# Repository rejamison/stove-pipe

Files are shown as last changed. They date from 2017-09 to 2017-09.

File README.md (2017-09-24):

# Stove Pipe

This project was to build an RGB LED hat with a 5 x 18 grid display for my daughter to wear at the 2017 Mini Maker Faire in Seattle.



The hat is powered by a Pi Zero W connected to a [FadeCandy](https://github.com/scanlime/fadecandy) to control the LEDs.  The hat's structure is 3D printed.

The LED animation code is written in Node.js and the project includes an iOS/Android app to control the hat using HTML5/JS in [Apache Cordova](https://cordova.apache.org/).

I spent about 4 hours actively coding and another 4 hours modeling the parts for 3D printing.  The entire project took about 7 days, mostly unmonitored printing, and another 2-3 hours for assembly.

## 3D Printing

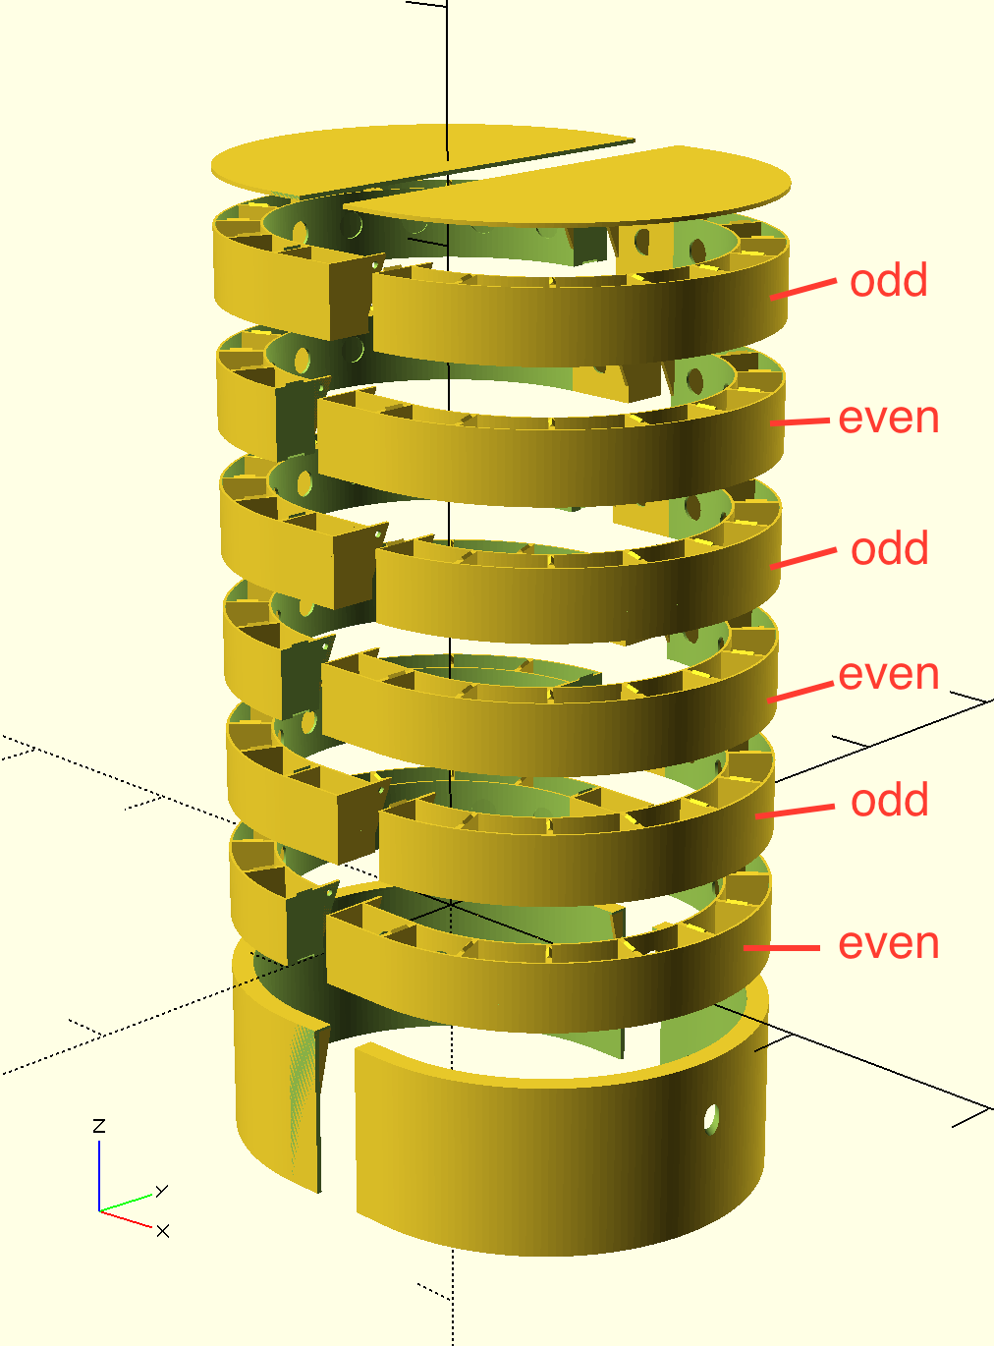
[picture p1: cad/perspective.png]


The hat is made up of 16 parts in 8 layers.  Each layer is split in two since I couldn't fit an entire ring onto my Ultimaker 2's 200x200 build plate.  The LED rings come in "odd" and "even" flavors so that the seam between halves doesn't line up between layers, making the assembled structure a bit sturdier.  If you have a larger printer, assembly could be greatly simplified by merging the halves of each layer together.

* red `top_half.stl`, red  `top_half.stl`
* green`ring_even_half.stl`, green `ring_even_half.stl`
* blue`ring_odd_half.stl`, blue `ring_odd_half.stl`
* green `ring_even_half.stl`, green `ring_even_half.stl`
* blue`ring_odd_half.stl`, blue `ring_odd_half.stl`
* green `ring_even_half.stl`, green `ring_even_half.stl`
* blue `ring_odd_half.stl`, blue `ring_odd_half.stl`
* yello `bottom_half_left.stl`, yello `bottom_half_right.stl`

`mount_plate.stl` is provided to mount the pi zero and fadecandy to, if desired.

STL files are located in the `cad/` sub-directory of the project and also on [Thingiverse](https://www.thingiverse.com/thing:2550326).

* Printed using white Polymaker Polymax PLA.
* 100% infill is required for even diffusion of the LEDs through the plastic.
* Full build with 6 LED layers requires ~1kg of filament.
* Sized for a 27" circumference, which accomodates a 23" head with room for ~1/2" padding, which is quite large.  You'll probably want to resize for your own head:
  * Figure out how big around your head is, then add 3" to the circumference to give room for about ~1/2" of padding.
  * Go to the OpenSCAD source file and play with the "pitch" parameter, which dictates the size of each LED cell in millimeters.  Smaller cells mean a smaller hat.
  * The "Outer Circumference in Inches" in the output console shows the current circumference based on the value you've set for "pitch".
  * Render each of the parts to STL files by commenting/uncommenting the appropriate module.

## Assembly

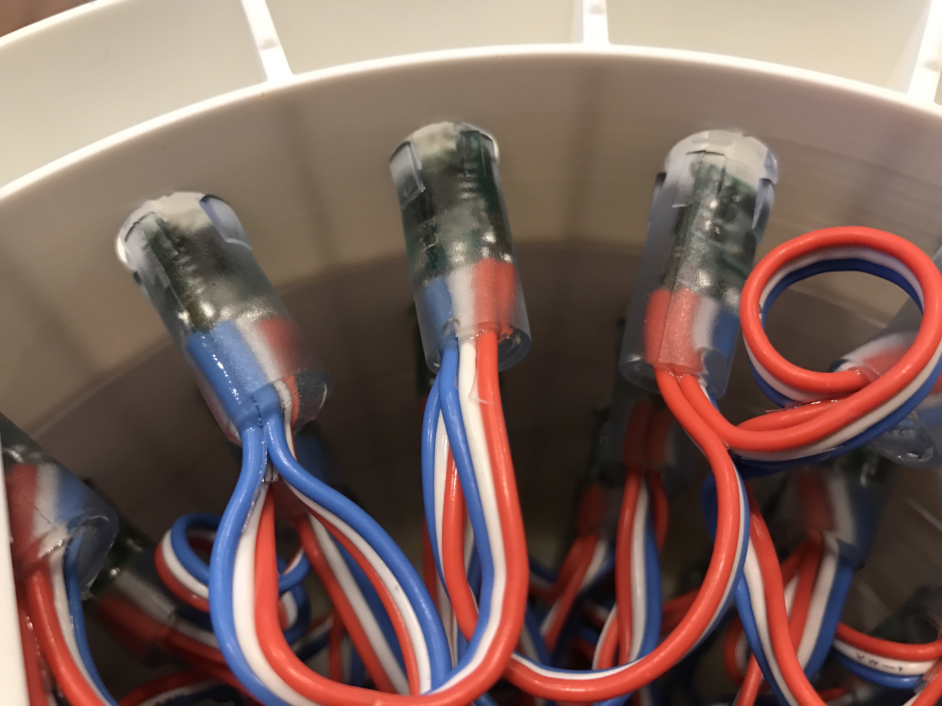
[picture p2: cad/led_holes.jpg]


Execept for the top, I glued the layers on top of each other with CA glue.  I used screws between the halves of the LED rings, but these weren't really necessary as the entire structure seemed to hold together well with just glue.  

Once the rings were assembled, I plugged the individual RGB LEDs on the strand into the holes in each cell.  The holes are sized to the built-in fastening tabs on the RGB strand I purchased, so no gluing necessary.  Be sure to layout the LEDs in a continuous spiral, starting at the top ring and as you complete a layer, being sure to start the next layer in the same column as the last.  The strands I purchased came with 50 LEDs, but I did NOT connect them end-to-end, since the FadeCandy addresses at most 64 LEDs on a single run.

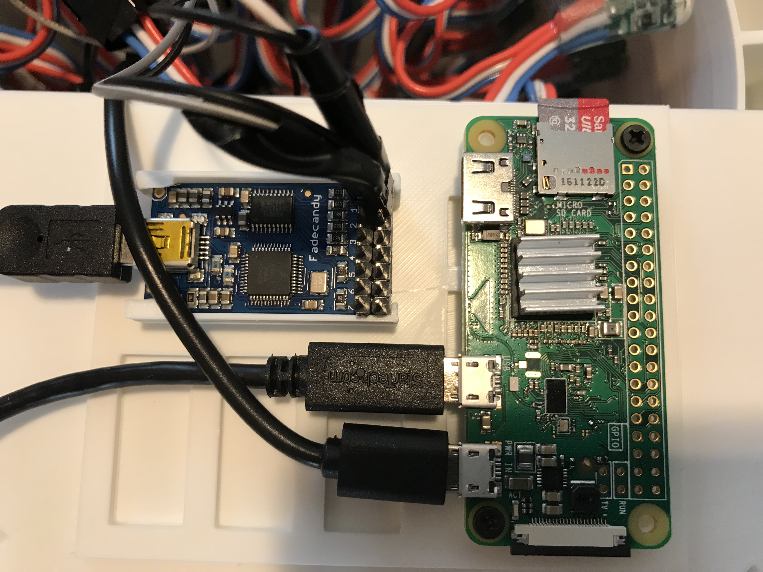
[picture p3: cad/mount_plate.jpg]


I soldered pin headers to the FadeCandy, rather than directly solder wires to the board, for easy future scavenging. 

I mounted the Pi using 2.5M screws to the mount plate and snapped in the FadeCandy.  They're connected to each other with a short Micro-USB to Mini-USB cable. 

The 0 and 1 LED banks of the FadeCandy each include a signal and ground connection.  The data pins of the first strand is connected to 0 and the second strand to 1.  

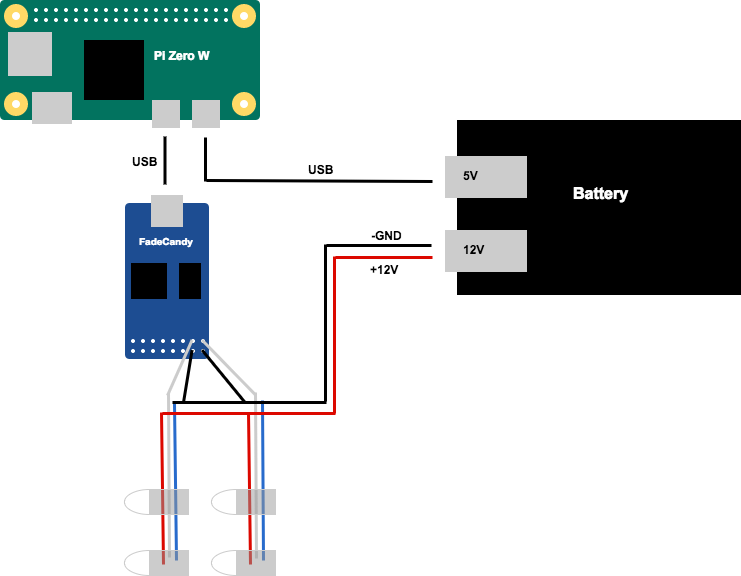
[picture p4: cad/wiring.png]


The FadeCandy ground pins should be shared with the ground of the LED strands, so I connected them to a terminal on a female 5.1mm x 2.1mm barrel jack connector.

The LED strands I chose use 12V vs. 5V, mostly because it was easier to get higher-amperage 12V batteries.  To create a 12V "rail", I connected both strands in parallel to the barrel jack, then connected a 6-foot extension to the jack.

Since the Pi uses 5V, I just connected a 6-foot Micro-USB to USB-B cable to the power connecter on the Pi.  I taped the 12V barrell jack and 5V USB cables together with some electrical tape to keep things tidy.  

**NOTE:  Since we're using both 12V and 5V, I recommend triple-checking your connections before applying power for the first time to avoid destroying your Pi.**

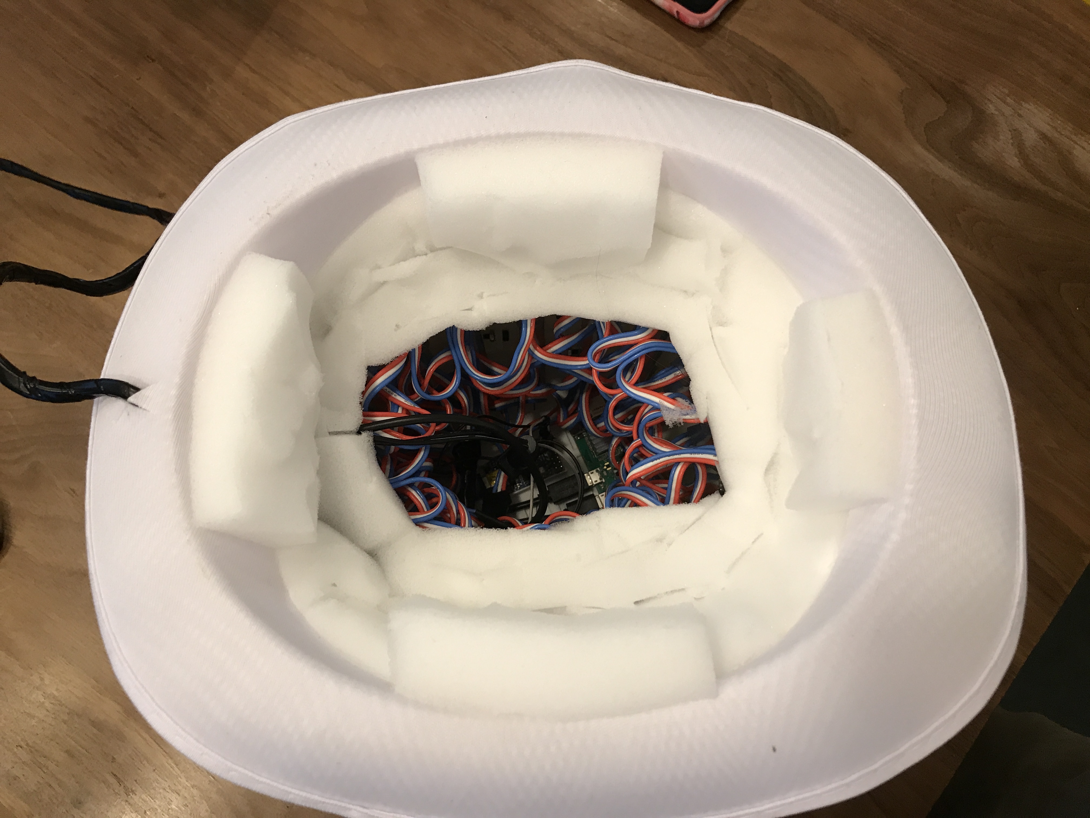
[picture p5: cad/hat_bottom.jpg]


I used high-density foam from a craft store to pad the bottom of the hat, cutting thin strips and building up layers as I tried it on my daughter's head until the fit was comfortable and stable.  

I used the brim of a cheap hat I bought on Amazon, cutting off the top of the hat and inserting the remainder into the bottom of the 3D printed tube.  This ended up being more trouble than it's worth, as it was finicky to fit right with its compound curve and ultimately made the top-heavy hat even more unstable.  For V2, I'd just print a brim, or tack on a bit of foam-board.

## Software Installation

I setup the Pi Zero W with the Raspian Stretch Lite image from [raspberrypi.org](https://www.raspberrypi.org/downloads/raspbian/), configuring wifi and enabling SSH in the `/boot/` image on the micro SD card before inserting it onto the pi.

After booting the Pi and SSH'ing in, I:
* Changed the password:  
  ```bash
  passwd
  ```
* Updated everything: 
  ```bash
  sudo apt-get update
  sudo apt-get upgrade
  ```
* Install git:  
  ```bash
  sudo apt-get install git
  ```
* [Install nvm](https://github.com/creationix/nvm#install-script).
* [Install node using nvm](https://github.com/creationix/nvm#usage).
* [Changed the hostname](https://thepihut.com/blogs/raspberry-pi-tutorials/19668676-renaming-your-raspberry-pi-the-hostname) to `stove-pipe`.

I grabbed the project code inside the `/home/pi` directory:

```bash
git clone git@github.com:rejamison/stove-pipe.git
cd stove-pipe
npm install
```

FadeCandy provides a server that gives you a web-based interface for interacting with the LEDs.  I [built the server](https://github.com/scanlime/fadecandy/tree/master/server).  To test things out, run the server in the background and try running the LED animation script:

```bash
cd /home/pi/fadecandy/server
fcserver &
cd /home/pi/stove-pipe
node index.js FadeCandy
```

You can also tell the animation script to render the animation to the console:

```bash
node index.js Console
```

If you're developing your own animations, I recommend doing so on your development machine and connecting remotely to the FadeCandy server on the Pi (vs. trying to develop locally on the Pi).  To do that, just modify the hostname in [index.js](https://github.com/rejamison/stove-pipe/blob/master/index.js) to your Pi's:

```javascript
var client = new OPC('stove-pipe.local', 7890);
```

**NOTE: Be careful about accidentally pushing this change up to the Pi.  It will work fine as long as it's connected to wifi, but you'll find it doesn't work if it's not able to connect to a network because the `.local` hostname won't route to anything.**
 
Once everything is good to go, I moved the binary to a global bin directory and set the server and my LED animation script to run on boot:

```bash
sudo mv fcserver /usr/local/bin
sudo nano /etc/rc.local
```

Adding the following to `rc.local` before the last `exit 0` line:

```bash
/usr/local/bin/fcserver /home/pi/stove-pipe/fcserver_config.json >/var/log/fcserver.log 2>&1 &
/home/pi/.nvm/versions/node/v8.5.0/bin/node /home/pi/stove-pipe/index.js FadeCandy
```

**NOTE:  You might need to adjust the node path above depending on what's the latest when you install using NVM.  You can figure it out by running: `which node`.**

Reboot the Pi and the animation should start running!

To control the hat, I built a BLE characteristic into the animation script to control which animation is playing and built a small mobile app to connect to the pi.  To build the app using Apache Cordova, from your development machine:
* [Setup Apache Cordova for iOS or Android](https://cordova.apache.org/docs/en/latest/).
* Grab the development project:  
  ```bash
  git clone git@github.com:rejamison/stove-pipe.git
  ```
* Install the app using cordova.  
  * For Android:  
    ```bash
    cd stove-pipe/app
    cordova platform add android
    cordova run android
    ```
  * For iOS:  
    ```bash
    cd stove-pipe/app
    cordova platform add ios
    cordova run ios
    ```

## Usage

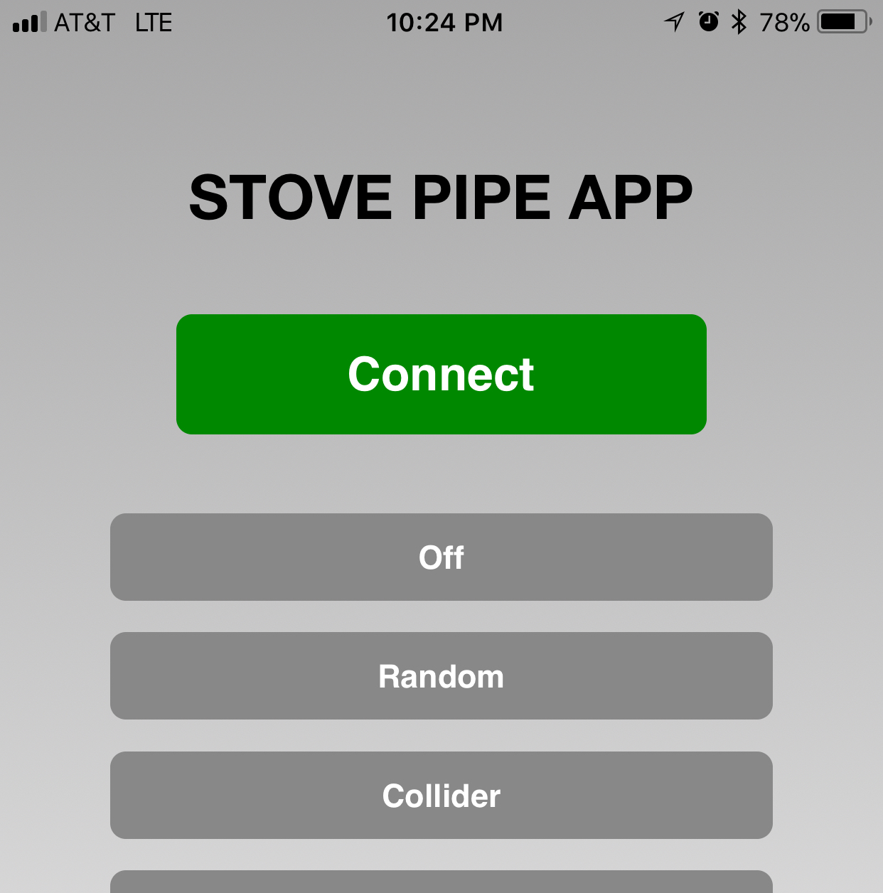
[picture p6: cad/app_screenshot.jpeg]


To use the app, just open it up on your device and click the "Connect" button.  After it connects, all the animation buttons should turn green and you should be able to switch the running animation by clicking any of the buttons.

If the app has trouble connecting, it may be because you're using a different hostname for the Pi.  You can change the `BT_DEVICE_NAME` parameter in the app's code [app/www/js/index.js](https://github.com/rejamison/stove-pipe/blob/master/app/www/js/index.js) or change the hostname of the device to `stove-pipe`.

## Bill of Materials

|Tools|
|---|
|CA Glue|
|Soldering Iron & Solder|
|Wire Cutters|
|Hobby Knife|

|Part|Qty|Cost Each|Total Cost|Link|Note|
|---|---|---|---|---|---|
|ALITOVE LED Strand (12V, 50 LEDs each)|2|$33|$66|[Amazon](https://www.amazon.com/ALITOVE-Individually-Addressable-Non-waterproof-Raspberry/dp/B014R5PC42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)||
|FadeCandy|1|$24|$24|[Amazon](https://www.amazon.com/Adafruit-FadeCandy-Dithering-USB-Controlled-NeoPixels/dp/B00JHJJF9W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)||
|Pi Zero W|1|$25|$25|[Amazon](https://www.amazon.com/CanaKit-Raspberry-Wireless-Official-Supply/dp/B071L2ZQZX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)|You don't need the case or power supply for this build, and can save $15 if you can find a barebones Zero W.|
|8GB Micro SD|1|$9|$9|[Amazon](https://www.amazon.com/gp/product/B010Q57SEE/ref=oh_aui_detailpage_o00_s00?ie=UTF8&psc=1)|8GB is overkill, but smaller wasn't really cheaper.|
|Micro USB to Mini USB Adapter|1|$4|$4|[Amazon](https://www.amazon.com/gp/product/B018M8YNDG/ref=od_aui_detailpages01?ie=UTF8&psc=1)|Wish they made smaller ones of these, and cheaper.  You could patch a cable together or even solder directly onto the FadeCandy board, but I prefered to keep this pluggable for future scavenging.|
|6" Mini USB Cable|1|$4|$4|[Amazon](https://www.amazon.com/gp/product/B00VU7PTKI/ref=oh_aui_detailpage_o02_s01?ie=UTF8&psc=1)||
|2.1mm x 5.5mm Male Jack|1|$1|$1|[Amazon](https://www.amazon.com/Wsdcam-5-5x2-1mm-Adapter-Connector-Security/dp/B0127J7NWE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)||
|6" Male/Female 2.1mm x 5.5mm Cable|1|$7|$7|[Amazon](https://www.amazon.com/gp/product/B00FTH6WNS/ref=oh_aui_detailpage_o02_s00?ie=UTF8&psc=1)|Begrudgingly bought this.  You could build your own cable, but considering the amperage it would carry, I decided to splurge.|
|TalentCell 12V@6A/5V@2A 26000mAh Li-Ion Battery|1|$65|$65|[Amazon](https://www.amazon.com/gp/product/B016BJCRUO/ref=oh_aui_detailpage_o07_s00?ie=UTF8&psc=1)|This is overkill, but I wanted a battery rated at 12V@6A to drive the LEDs at peak brightness.  The capacity means the hat can run all-day, maybe a couple of days.  Here's a cheaper one for $34 (and lighter too) rated for 12V@3A and 12000mAk, you'll just need to reduce the LED brightness:  [Amazon](https://www.amazon.com/TalentCell-Rechargeable-12000mAh-Multi-led-indicator/dp/B00ME3ZH7C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).  The battery is a handy component and easily re-used, so I consider it an investment.|
|White Top Hat|1|$9|$9|[Amazon](https://www.amazon.com/gp/product/B003E98N9O/ref=oh_aui_detailpage_o03_s00?ie=UTF8&psc=1)|See above, I attempted to use this for it's brim, but would just 3D print one instead.|
|High Density Foam Padding|1|$12|$12|[Amazon](https://www.amazon.com/FoamTouch-Upholstery-Cushion-Density-Height/dp/B01K01HJZM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)||
|White Polymaker Polymax 750g|1|$46|$46|[Printed Solid](https://printedsolid.com/products/polymaker-polymax-pla-3mm-x-750g?variant=35756291468)|Polymaker is my go-to filament, by no means the cheapest you can get.  Used nearly an entire spool of 750g for this build.|
|2.5M Screws|1|$0|$0|[Amazon](https://www.amazon.com/Slaxry-Notebook-Laptop-SAMSUNG-TOSHIBA/dp/B01M04WWVV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)|2.5M screws are a little hard to find, but an easy way to get them is to buy a screw kit assortment for laptops for a few dollars on Amazon.  I find the other sizes included to be pretty handy for projects.|
||||**$272**||

Prices as of 9/17/17.

Wow, more than I expected before adding it up.  Of course, I had most of this stuff laying around, so my only real outlay was the LED strands and the cables.  Everything is scavengable except the filament.

If I were building it again, I'd probably switch to an LED strip, which is a lot cheaper per LED (~$15 / 100 LEDs vs. $66 / 100 LEDs) and would weigh quite a bit less.  The cheaper battery, DIY cables, a barebones Pi Zero W and ditching the hat saves another $66, for a hypothetical total of $165.

If you're really looking for a cheap project, then you can get 1kg of cheap PLA for ~$25 and switch to a nano Arduino for ~$5 and skip the FadeCandy, though you'd have to roll your own code and drop the BLE support.  That gets the project into the ~$90-100 range which is mostly battery, filament and LEDs.

## Future Ideas

I'll probably never get to these, but here's some stuff I'd do with more time:

* Add a BLE characteristic that allows you to shutdown the Pi cleanly.
* Switch to an LED strip, instead of the bulky strands.

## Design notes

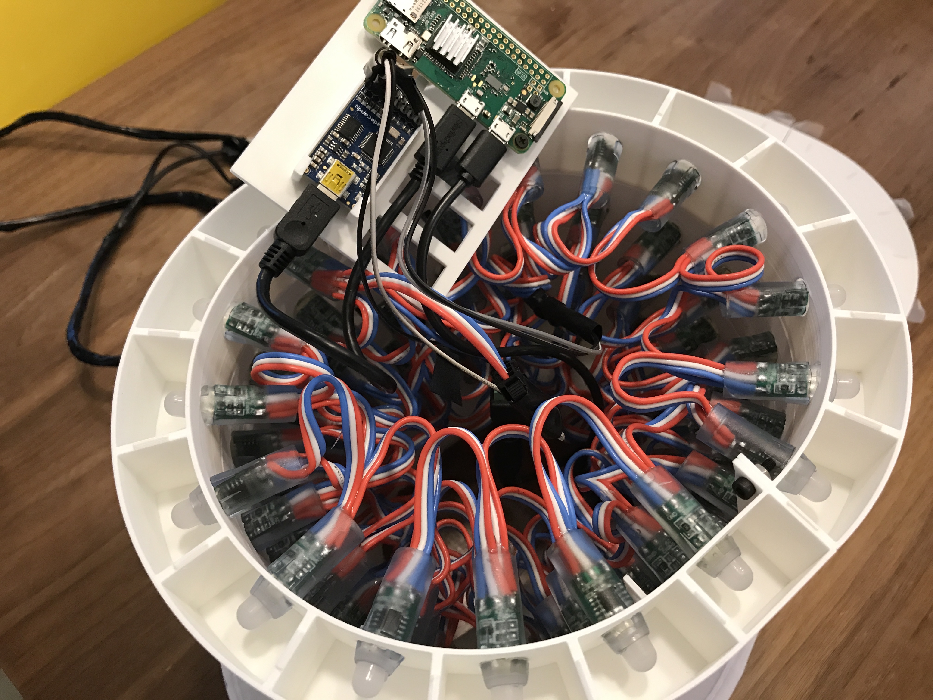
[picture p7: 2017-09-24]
cad/hat_top.jpg

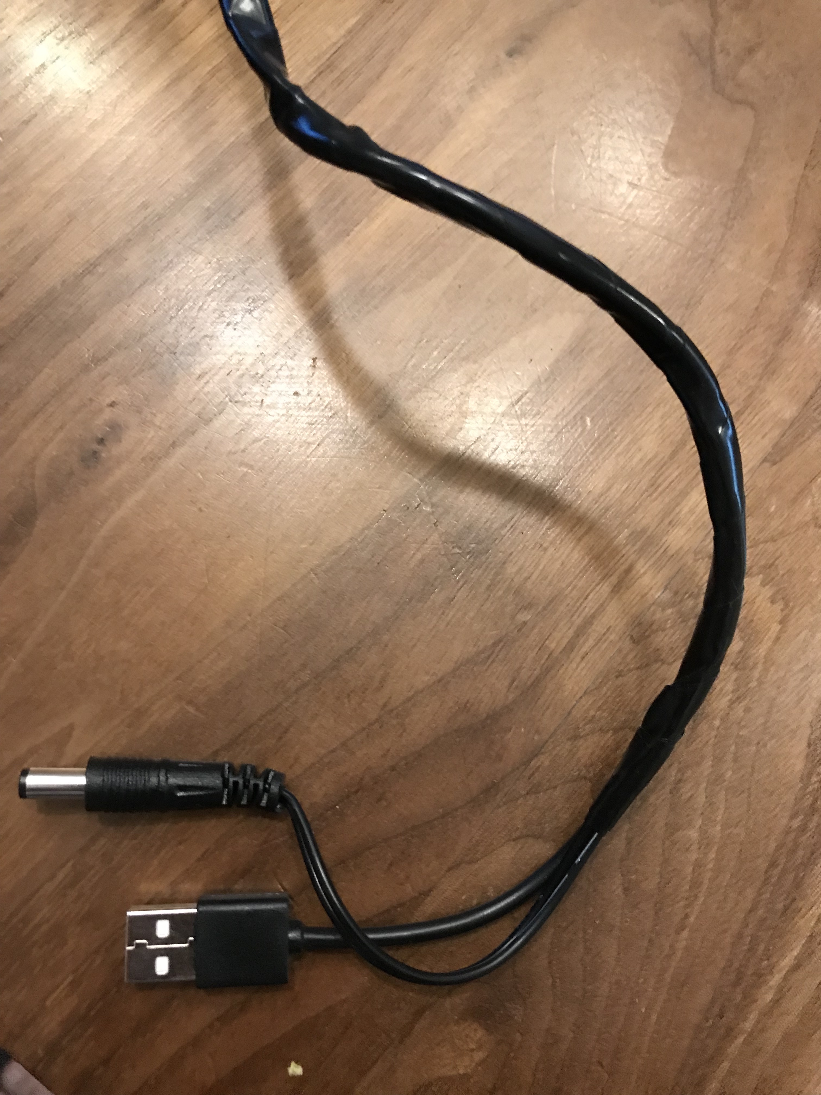
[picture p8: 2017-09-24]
cad/wrapped_cable.jpg

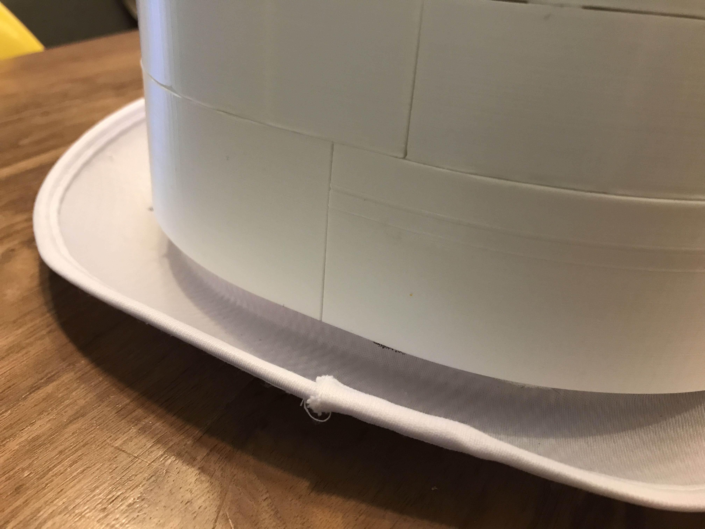
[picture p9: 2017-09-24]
cad/hat_brim.jpg

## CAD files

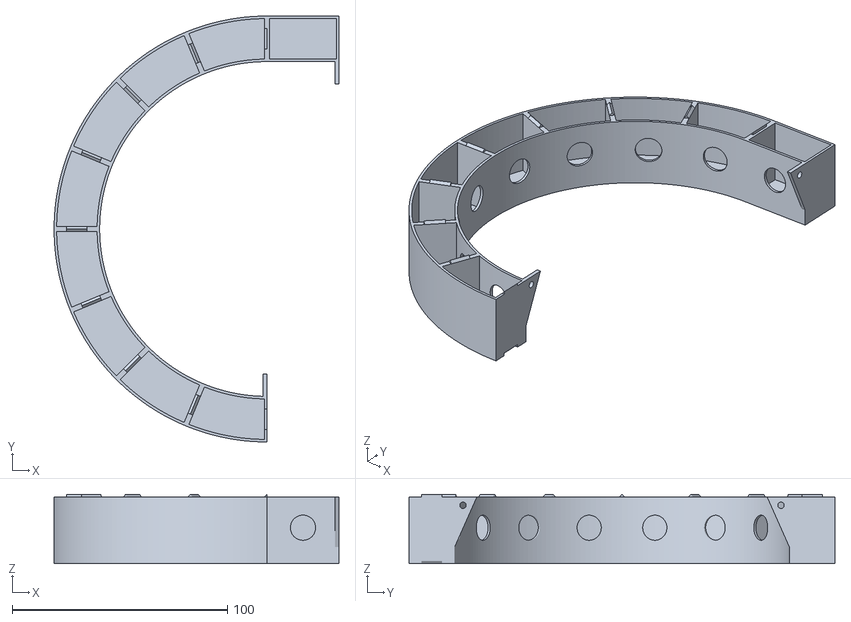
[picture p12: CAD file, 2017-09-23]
cad/ring_even_half.stl
132.3 x 197.9 x 32.2

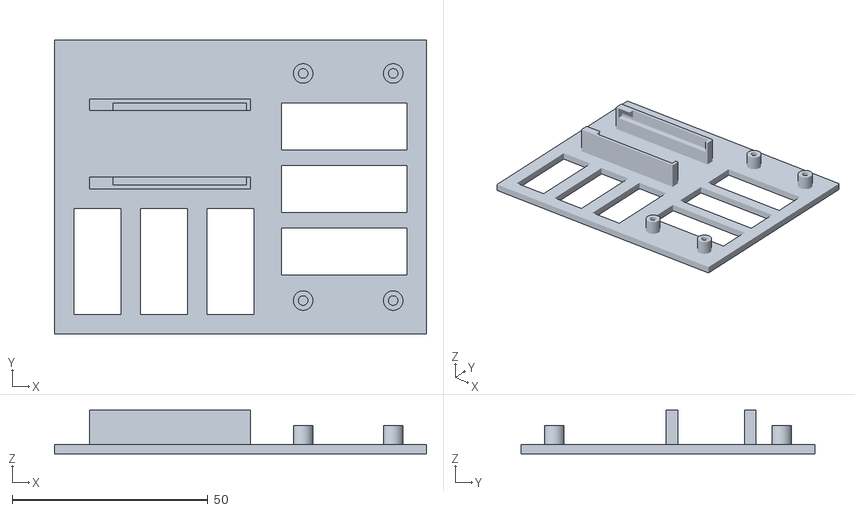
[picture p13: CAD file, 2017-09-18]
cad/mount_plate.stl
95.0 x 75.0 x 11.2

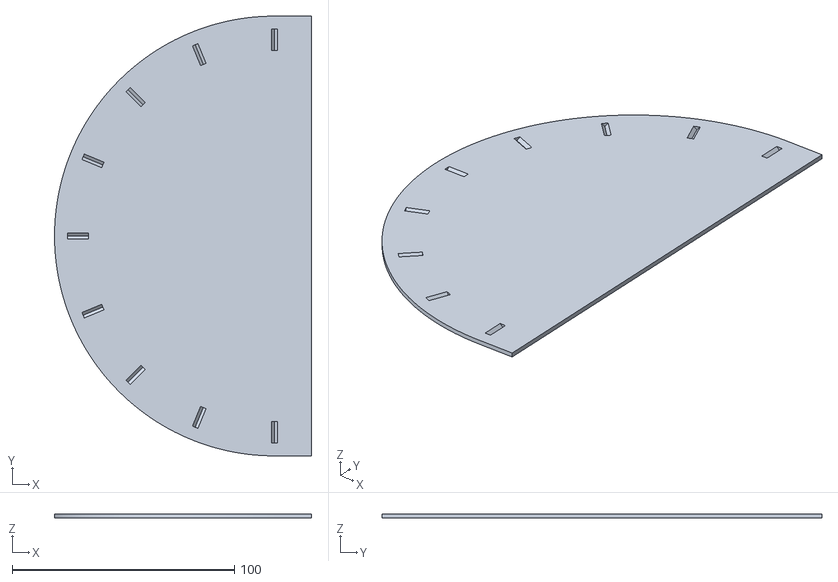
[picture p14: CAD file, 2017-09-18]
cad/top_half.stl
115.6 x 197.9 x 1.80

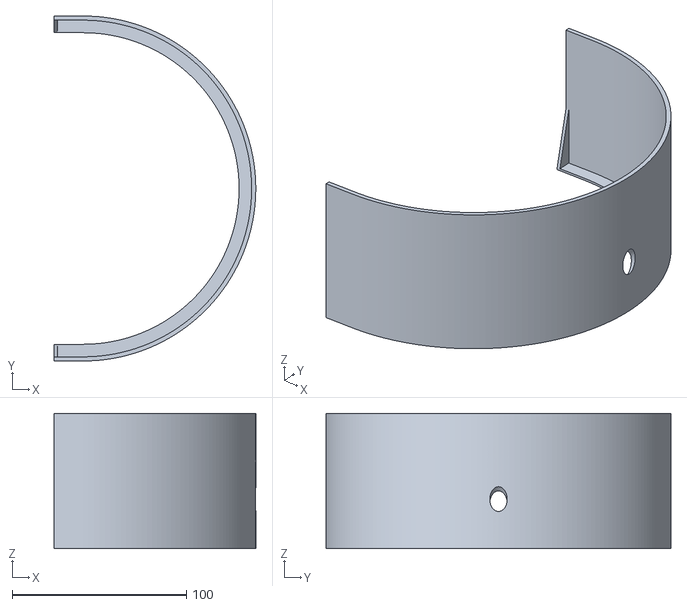
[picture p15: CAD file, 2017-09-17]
cad/bottom_half_right.stl
115.6 x 197.9 x 77.5

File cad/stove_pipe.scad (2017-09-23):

$fn = 200;

pitch = 31;
led_per_stack = 1;
height = pitch * led_per_stack;
led_per_layer = 16;
inner_radius = (pitch * led_per_layer) / (2 * 3.14159);
wall_depth = 1.2;
led_radius = (11.5+.2)/2;
led_cell_depth=20;
notch_diag=(wall_depth*2);
notch_height=(notch_diag)/1.4142;

echo("Inner Diameter in MM", (inner_radius * 2));
echo("Outer Diameter in MM", ((inner_radius + 10) * 2));
echo("Outer Circumference in Inches", (((inner_radius + led_cell_depth) * 2 * 3.14159) + (pitch * 2)) / 25.4);

//ring_even_half_left();
//ring_even_half_right();  // same as left, just rotated and translated
ring_odd_half_left();
//ring_odd_half_right();  // same as left just rotated and translated
//top_half_left();
//top_half_right();  // same as left, just rotated and translated
//mount_plate();
//alt_bottom_half_left();
//alt_bottom_half_right();  // this one is different, as it includes a hole for a cable to pass through

//exploded();

module exploded() {
    gap = 25;

    translate([0,0,0]) ring_even_half_left();
    translate([gap,0,0]) ring_even_half_right();

    translate([0,0,height + gap]) ring_odd_half_left();
    translate([gap,0,height + gap]) ring_odd_half_right();

    translate([0,0,(height + gap) * 2]) ring_even_half_left();
    translate([gap,0,(height + gap) * 2]) ring_even_half_right();

    translate([0,0,(height + gap) * 3]) ring_odd_half_left();
    translate([gap,0,(height + gap) * 3]) ring_odd_half_right();

    translate([0,0,(height + gap) * 4]) ring_even_half_left();
    translate([gap,0,(height + gap) * 4]) ring_even_half_right();

    translate([0,0,(height + gap) * 5]) ring_odd_half_left();
    translate([gap,0,(height + gap) * 5]) ring_odd_half_right();

    translate([0,0,(height + gap) * 6]) rotate([180,0,0]) top_half_left();
    translate([gap,0,(height + gap) * 6]) rotate([180,0,0]) top_half_right();
    
    translate([0,0,-gap]) rotate([180,0,0])  alt_bottom_half_left();
    translate([gap,0,-gap]) rotate([180,0,0]) alt_bottom_half_right();
}

module bottom_half_left() {
    difference() {
        union() {
            cylinder(r=inner_radius+led_cell_depth,h=pitch*1.5);
            translate([0,-(inner_radius+led_cell_depth),0]) cube([(pitch/2)+wall_depth, (inner_radius+led_cell_depth) * 2, pitch*1.5]);
        }
        translate([0,0,pitch/2-.01]) cylinder(r1=inner_radius-wall_depth, r2=inner_radius-wall_depth*4+led_cell_depth ,h=pitch+.02);
        translate([0,0,-.01]) cylinder(r=inner_radius-wall_depth,h=pitch+.02);
        translate([(pitch/2)+wall_depth,-(inner_radius+led_cell_depth),-1]) cube([500, (inner_radius+led_cell_depth) * 2, pitch*1.5+2]);
        translate([0,-(inner_radius-wall_depth),-1]) cube([500, (inner_radius-wall_depth) * 2, pitch+2]);
        translate([0+.01,inner_radius-wall_depth-.01,pitch/2-.01]) rotated_prism((pitch/2)+wall_depth,led_cell_depth-wall_depth*3,pitch+.02,180,0,0);
        translate([0+.01,-inner_radius+wall_depth-led_cell_depth+wall_depth*3+.01,pitch/2-.01]) rotated_prism((pitch/2)+wall_depth,led_cell_depth-wall_depth*3,pitch+.02,180,0,180);
    }
}

module bottom_half_right() {
    difference() {
        translate([pitch+wall_depth*2,0,0]) rotate([0,0,180]) bottom_half_left();
        translate([inner_radius-6,0,-pitch]) rotate([0,45,0]) cylinder(d=10,h=100);
    }
}

module alt_bottom_half_left() {
    difference() {
        union() {
            cylinder(r=inner_radius+led_cell_depth,h=pitch*2.5);
            translate([0,-(inner_radius+led_cell_depth),0]) cube([(pitch/2)+wall_depth, (inner_radius+led_cell_depth) * 2, pitch*2.5]);
        }
        translate([0,0,wall_depth-.01]) cylinder(r=inner_radius-wall_depth*2+led_cell_depth ,h=pitch*2.5+.02);
        translate([0,0,-.01]) cylinder(r=inner_radius-wall_depth*8+led_cell_depth,h=pitch+.02);
        translate([(pitch/2)+wall_depth,-(inner_radius+led_cell_depth),-1]) cube([500, (inner_radius+led_cell_depth) * 2, pitch*2.5+2]);
        translate([0,-(inner_radius+led_cell_depth-wall_depth*2),wall_depth]) cube([100, (inner_radius+led_cell_depth-wall_depth*2) * 2, pitch*2.5+2]);
        translate([0,-(inner_radius+led_cell_depth-wall_depth*8),-1]) cube([100, (inner_radius+led_cell_depth-wall_depth*8) * 2, pitch*2.5+2]);
    }
    // tabs
    translate([pitch/2-wall_depth*.5,(inner_radius+led_cell_depth-wall_depth*8),wall_depth]) rotated_prism(wall_depth*1.5,wall_depth*6,height,0,0,0);
    translate([pitch/2-wall_depth*.5,-(inner_radius+led_cell_depth-wall_depth*2),wall_depth]) rotated_prism(wall_depth*1.5,wall_depth*6,height,0,0,180);
}

module alt_bottom_half_right() {
    difference() {
        translate([pitch+wall_depth*2,0,0]) rotate([0,0,180]) alt_bottom_half_left();
        translate([inner_radius-6,0,-pitch]) rotate([0,45,0]) cylinder(d=10,h=100);
    }
}

module top_half_left() {
    difference() {
        union() {
            cylinder(r=inner_radius+led_cell_depth,h=wall_depth*1.5);
            translate([0,-(inner_radius+led_cell_depth),0]) cube([pitch/2+wall_depth, (inner_radius+led_cell_depth) * 2, wall_depth*1.5]);
        }
        translate([pitch/2+wall_depth,-(inner_radius+led_cell_depth),-1]) cube([500, (inner_radius+led_cell_depth) * 2, wall_depth*1.5+2]);
        for(i = [0:1:led_per_layer - 1]) {
            translate([0,0,wall_depth*1.5]) rotate([45,0,i * (360 / led_per_layer)]) translate([inner_radius+((led_cell_depth-wall_depth)/4)-.1,-(notch_height)/2-.1,-(notch_height)/2-.1]) cube([(led_cell_depth-wall_depth)/2+.2,notch_height+.2,notch_height+.2]);
        }
    }
}

module top_half_right() {
    translate([pitch+wall_depth*2,0,0]) rotate([0,0,180]) top_half_left();
}

module mount_plate() {
    difference() {
        translate([-60,-55,0]) cube([95,75,wall_depth*2]);
        translate([-2,-8,-.1]) cube([32,12,50]);
        translate([-2,-24,-.1]) cube([32,12,50]);
        translate([-2,-40,-.1]) cube([32,12,50]);
        translate([-55,-50,-.1]) cube([12,27,50]);
        translate([-38,-50,-.1]) cube([12,27,50]);
        translate([-21,-50,-.1]) cube([12,27,50]);
    }
    translate([-10,5,wall_depth]) rotate([0,0,180]) fadecandy_mount();
    translate([30,-50,wall_depth]) rotate([0,0,90]) pi_zero_mount();
}

module fadecandy_mount() {
    difference() {
        cube([41,23,10]);
        translate([1,1,6]) cube([39,21,10]);
        translate([-1,3,-1]) cube([43,17,12]);
    }
    translate([35,19.5,7.5]) rotated_prism(5, 3, 2, 90, 0 ,0);
    translate([35,0.5,7.5]) rotated_prism(5, 3, 2, 90, 0, 180);
}

module pi_zero_mount() {
    translate([0+3.5,0+3.5,0]) difference() {
        cylinder(d=5,h=6);
        translate([0,0,-.01]) cylinder(d=2.45,h=6+.02);
    }
    translate([58+3.5,0+3.5,0]) difference() {
        cylinder(d=5,h=6);
        translate([0,0,-.01]) cylinder(d=2.45,h=6+.02);
    }
    translate([0+3.5,23+3.5,0]) difference() {
        cylinder(d=5,h=6);
        translate([0,0,-.01]) cylinder(d=2.45,h=6+.02);
    }
    translate([58+3.5,23+3.5,0]) difference() {
        cylinder(d=5,h=6);
        translate([0,0,-.01]) cylinder(d=2.45,h=6+.02);
    }
}

module ring_even_half_left() {
    difference() {
        union() {
            // outer ring
            difference() {
                cylinder(r=inner_radius+led_cell_depth,h=height);
                translate([0,0,-1]) cylinder(r=inner_radius+led_cell_depth-wall_depth,h=height+2);
            }

            // inner ring and ribs
            difference() {
                union() {
                    cylinder(r=inner_radius,h=height);
                    for(i = [0:1:led_per_layer - 1]) {
                        rotate([0,0,i * (360 / led_per_layer)]) translate([inner_radius-wall_depth,-(wall_depth),0]) cube([led_cell_depth,wall_depth*2,height]);
                        translate([0,0,height]) rotate([45,0,i * (360 / led_per_layer)]) translate([inner_radius+((led_cell_depth-wall_depth)/4),-(notch_height)/2,-(notch_height)/2]) cube([(led_cell_depth-wall_depth)/2,notch_height,notch_height]);
                    }
                    for(i = [0:1:led_per_stack - 1]) {
                        translate([0,0,pitch*i]) cylinder(r=inner_radius+led_cell_depth,h=wall_depth*2);
                    }
                }
                translate([0,0,-1]) cylinder(r=inner_radius-wall_depth,h=height+10);
                for(i = [0:1:led_per_layer - 1]) {
                    rotate([45,0,i * (360 / led_per_layer)]) translate([inner_radius+((led_cell_depth-wall_depth)/4)-.1,-(notch_height)/2-.1,-(notch_height)/2-.1]) cube([(led_cell_depth-wall_depth)/2+.2,notch_height+.2,notch_height+.2]);
                    rotate([90,0,(360 / led_per_layer) * (i + 0.5)]) translate([0,pitch/2 + wall_depth,wall_depth]) cylinder(r=led_radius,h=inner_radius);
                }
            }
        } 
        
        translate([0,-100,-100]) cube([200,200,200]);
    }
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

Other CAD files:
cad/ring_odd_half.stl
cad/bottom_half_left.stl

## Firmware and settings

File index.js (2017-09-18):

var process = require('process');
var chalk = require('chalk');
var OPC = require('./opc');
var bleno = require('bleno');
var StovePipeCharacteristic = require('./characteristic');

var FRAME_RATE = 12;
var font = [
    "  X   XXXX   XXXX XXX   XXXX  XXXXX  XXX  X   X  XXX      X X  X  X     X   X X   X  XXX  XXX    XXX  XXXX   XXX  XXXXX X   X X   X X   X X   X X   X XXXXX ",
    " X X  X   X X     X  X  X     X     X   X X   X   X       X X X   X     XX XX XX  X X   X X  X  X   X X   X XX      X   X   X X   X X   X  X X   X X     X  ",
    "XXXXX XXXX  X     X   X XXX   XXX   X     XXXXX   X       X XX    X     X X X X X X X   X XXX   X   X XXXX   XX     X   X   X  X X  X X X   X     X     X   ",
    "X   X X   X X     X  X  X     X     X  XX X   X   X   X   X X X   X     X   X X  XX X   X X     X  XX X  X     XX   X   X   X   X   XX XX  X X    X    X    ",
    "X   X XXXX   XXXX XXX   XXXX  X      XXX  X   X  XXX   XXX  X  X  XXXXX X   X X   X  XXX  X      XXXX X   X  XXX    X    XXX    X    X X  X   X   X   XXXXX "
];
var pacman = [
    "  XXX     XXXX  ",
    " XXXXX   XXXX   ",
    "XXXXXXX XXX     ",
    " XXXXX   XXXX   ",
    "  XXX     XXXX  "
];
var client = new OPC('127.0.0.1', 7890);

function hsvToRgb(h, s, v) {
    var r, g, b, i, f, p, q, t;
    if (arguments.length === 1) {
        s = h.s, v = h.v, h = h.h;
    }
    i = Math.floor(h * 6);
    f = h * 6 - i;
    p = v * (1 - s);
    q = v * (1 - f * s);
    t = v * (1 - (1 - f) * s);
    switch (i % 6) {
        case 0: r = v, g = t, b = p; break;
        case 1: r = q, g = v, b = p; break;
        case 2: r = p, g = v, b = t; break;
        case 3: r = p, g = q, b = v; break;
        case 4: r = t, g = p, b = v; break;
        case 5: r = v, g = p, b = q; break;
    }
    return new RGB(Math.round(r * 255), Math.round(g * 255), Math.round(b * 255));
}

function RGB(r, g, b) {
    this.r = r;
    this.g = g;
    this.b = b;
}

function Canvas() {
    this.buffer = [
        [new RGB(255,255,255),new RGB(255,255,255),new RGB(255,255,255),new RGB(255,255,255),new RGB(255,255,255),new RGB(255,255,255),new RGB(255,255,255),new RGB(255,255,255),new RGB(255,255,255),new RGB(255,255,255),new RGB(255,255,255),new RGB(255,255,255),new RGB(255,255,255),new RGB(255,255,255),new RGB(255,255,255),new RGB(255,255,255),new RGB(255,255,255),new RGB(255,255,255)],
        [new RGB(255,255,255),new RGB(255,255,255),new RGB(255,255,255),new RGB(255,255,255),new RGB(255,255,255),new RGB(255,255,255),new RGB(255,255,255),new RGB(255,255,255),new RGB(255,255,255),new RGB(255,255,255),new RGB(255,255,255),new RGB(255,255,255),new RGB(255,255,255),new RGB(255,255,255),new RGB(255,255,255),new RGB(255,255,255),new RGB(255,255,255),new RGB(255,255,255)],
        [new RGB(255,255,255),new RGB(255,255,255),new RGB(255,255,255),new RGB(255,255,255),new RGB(255,255,255),new RGB(255,255,255),new RGB(255,255,255),new RGB(255,255,255),new RGB(255,255,255),new RGB(255,255,255),new RGB(255,255,255),new RGB(255,255,255),new RGB(255,255,255),new RGB(255,255,255),new RGB(255,255,255),new RGB(255,255,255),new RGB(255,255,255),new RGB(255,255,255)],
        [new RGB(255,255,255),new RGB(255,255,255),new RGB(255,255,255),new RGB(255,255,255),new RGB(255,255,255),new RGB(255,255,255),new RGB(255,255,255),new RGB(255,255,255),new RGB(255,255,255),new RGB(255,255,255),new RGB(255,255,255),new RGB(255,255,255),new RGB(255,255,255),new RGB(255,255,255),new RGB(255,255,255),new RGB(255,255,255),new RGB(255,255,255),new RGB(255,255,255)],
        [new RGB(255,255,255),new RGB(255,255,255),new RGB(255,255,255),new RGB(255,255,255),new RGB(255,255,255),new RGB(255,255,255),new RGB(255,255,255),new RGB(255,255,255),new RGB(255,255,255),new RGB(255,255,255),new RGB(255,255,255),new RGB(255,255,255),new RGB(255,255,255),new RGB(255,255,255),new RGB(255,255,255),new RGB(255,255,255),new RGB(255,255,255),new RGB(255,255,255)],
    ];

    this.animationIndex = 0;
    this.height = this.buffer.length;
    this.width = this.buffer[0].length;
    this.shouldConsole = false;
    this.shouldFadeCandy = false;
    this.animations = [];

    this.initialize = function(renderToConsole, renderToFadeCandy) {
        console.log('Width: ' + this.width);
        console.log('Height: ' + this.height);
        this.shouldConsole = renderToConsole ? true : false;
        this.shouldFadeCandy = renderToFadeCandy ? true : false;

        bleno.on('stateChange', function(state) {
            console.log('on -> stateChange: ' + state);

            if (state === 'poweredOn') {
                bleno.startAdvertising('stove-pipe', ['ec00']);
            } else {
                bleno.stopAdvertising();
            }
        });

        var that = this;
        bleno.on('advertisingStart', function(error) {
            console.log('on -> advertisingStart: ' + (error ? 'error ' + error : 'success'));

            if (!error) {
                bleno.setServices([
                    new bleno.PrimaryService({
                        uuid: 'ec00',
                        characteristics: [
                            new StovePipeCharacteristic(that)
                        ]
                    })
                ]);
            }
        });

        if(this.shouldConsole) {
            // spit out some newlines for rendering to the console
            for(var x = 0; x < this.height; x++) {
                process.stdout.write('\n');
            }
        }

        this.animations.push(new Random());             // 0    0x00
        this.animations.push(new Collider());           // 1    0x01
        this.animations.push(new PulsingPixels());      // 2    0x02
        this.animations.push(new RotatingRainbow());    // 3    0x03
        this.animations.push(new Equalizer());          // 4    0x04
        this.animations.push(new GrowingLine());        // 5    0x05
        this.animations.push(new RacingDot());          // 6    0x06
        this.animations.push(new RacingLine());         // 7    0x07
        this.animations.push(new ScrollingText('MAKER FAIRE', new RGB(255,0,0)));
        this.animations.push(new ScrollingText('PENELOPE RULES', new RGB(0,0,255)));
        this.animations.push(new Rain());               // 10   0x0A
        this.animations.push(new Fireworks());          // 11   0x0B
        this.animations.push(new Pacman());             // 12   0x0C
        this.animations.push(new Off());                // 13   0x0D
        this.animations.push(new ScrollingTextRainbow('PARTY TIME'));

        this.animations[this.animationIndex].initialize(this);
    };

    this.switchToAnimation = function(index) {
        if(index >= 0 && index < this.animations.length) {
            this.animationIndex = index;
            this.animations[this.animationIndex].initialize(this);
        } else {
            // do nothing
        }
    };

    this.run = function() {
        this.oneFrame();
    };
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

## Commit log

2017-09-14 Added a couple of animations.
2017-09-15 Fixed bug with neopixel addressing.
    [index.js]
2017-09-16 Added OpenSCAD model.
    [hat_v2.scad]
2017-09-16 Updated CAD models.
    [hat_v2.scad, hat_v2_inv.stl]
2017-09-16 Added an alternate bottom part to optimize for print speed using hand-cut materials.
    [hat_v2.scad, hat_v2_alt_bottom_half_left.stl, hat_v2_alt_bottom_half_right.stl]
2017-09-16 Added second LED strand to config.
2017-09-16 Fixed bug in Random animation where it was switching each frame.
    [index.js]
2017-09-17 Added top and mount plate CAD models.
    [hat_v2.scad]
2017-09-17 Optimized the top model to minimize print time.
    [hat_v2.scad, hat_v2_alt_bottom_half_left.stl, hat_v2_alt_bottom_half_right.stl]
2017-09-18 Added stub Cordova app for controlling the hat over BLE.
    [hat_v2_mount_plate.stl, hat_v2_top_half.stl]
2017-09-23 Cleaned up CAD dir filenames.
    [bottom_half_left.stl, bottom_half_right.stl, hat_v2.scad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]
